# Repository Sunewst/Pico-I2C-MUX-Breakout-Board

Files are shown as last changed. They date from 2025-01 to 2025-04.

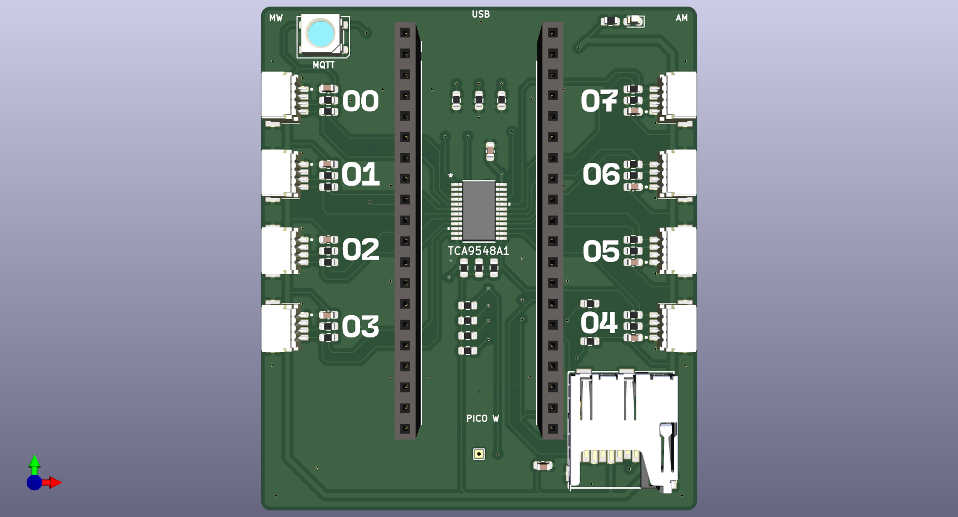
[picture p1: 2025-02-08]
Pico_STEMMA_HAT.png

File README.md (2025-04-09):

Showcase

<div align="center">

## Raspberry Pi Pico/W Breakout MUX Board

This PCB designed in KiCAD allows a Raspberry Pi Pico W, or normal version, to communicate with 8 I2C devices that have matching addresses. This board is based on breakout muiltiplexers sold by [Adafruit](https://www.adafruit.com/product/5626) and [SparkFun](https://www.sparkfun.com/sparkfun-qwiic-mux-breakout-8-channel-tca9548a.html). 

This also means the licence from these muiltiplexers, Creative Commons, applies to this one aswell.

</div>

---

## Arduino and CircuitPython
This breakout board works with either Arduino or CircuitPython.
> [!NOTE]
> For CircuitPython, I would recommend using the [libraries created by Adafruit for TCA9548a MUX use](https://learn.adafruit.com/adafruit-pca9548-8-channel-stemma-qt-qwiic-i2c-multiplexer/circuitpython-python).

The main connection are

SDA: GP4

SCL: GP5

MISO: GP16

MOSI: GP19

CLK: GP18

CS: GP17

Neopixel: GP6

---

## Creating and Changing this Design
1. Download the zip of this repo or clone it

2. Open the KiCAD project file.
> [!NOTE]
> This project was updated to KiCAD 9.0.

3. Examine and understand the schematic and PCB layout
> [!NOTE]
> The 3D models for the certain components might need to have their file path updated and their 3D models posistion adjusted to appear correctly on your PC.

4. Use your preferred PCB manufacture to order the PCB

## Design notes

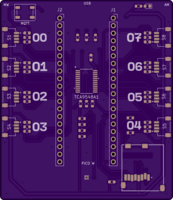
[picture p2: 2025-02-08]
STEMMA_HAT_FRONT.png

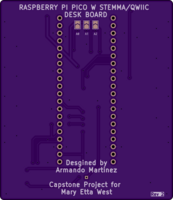
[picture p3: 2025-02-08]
STEMMA_HAT_BACK.png

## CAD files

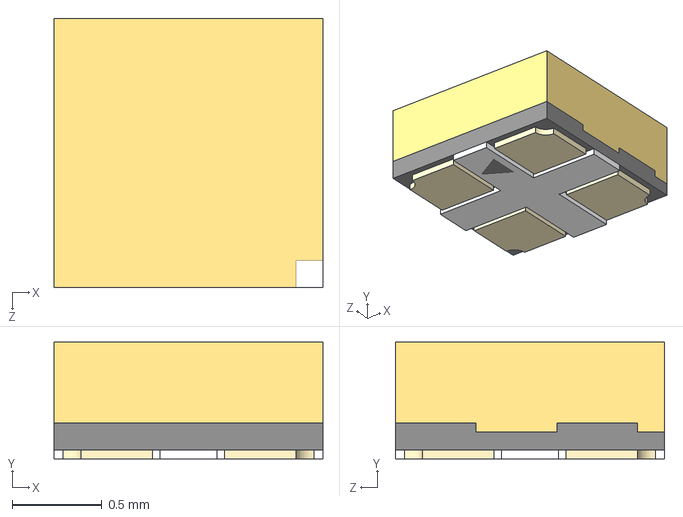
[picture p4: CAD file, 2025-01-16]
REIMAGINED_3D_FILES_BLENDER/4492.step
1.50 x 0.65 x 1.50 mm

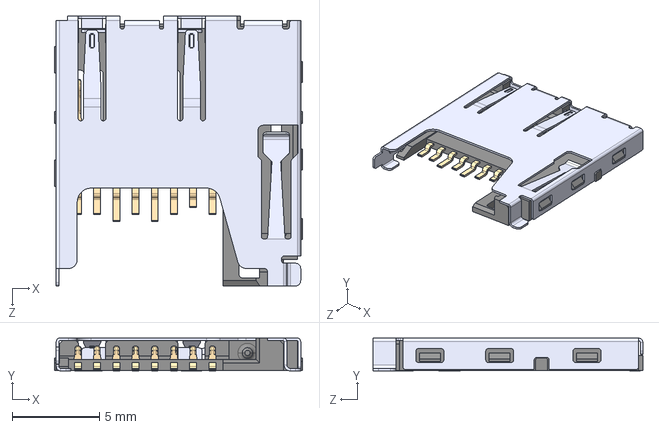
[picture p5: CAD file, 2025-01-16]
REIMAGINED_3D_FILES_BLENDER/MEM2061-01-188-00-A_REVA.step
14.2 x 1.88 x 15.4 mm

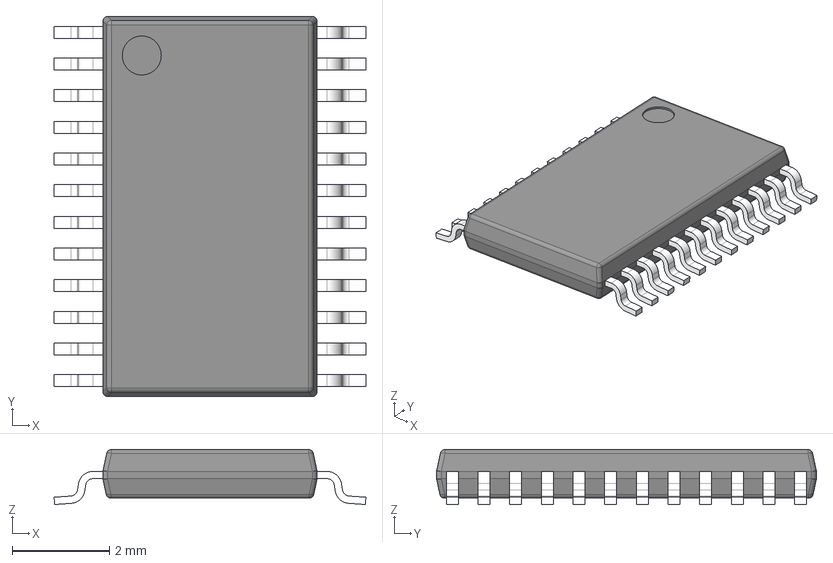
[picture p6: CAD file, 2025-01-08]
REIMAGINED_3D_FILES_BLENDER/PW0024A.stp
6.40 x 7.80 x 1.13 mm
BODY-TSSOP
LEAD-TSSOP x 24
PIN1

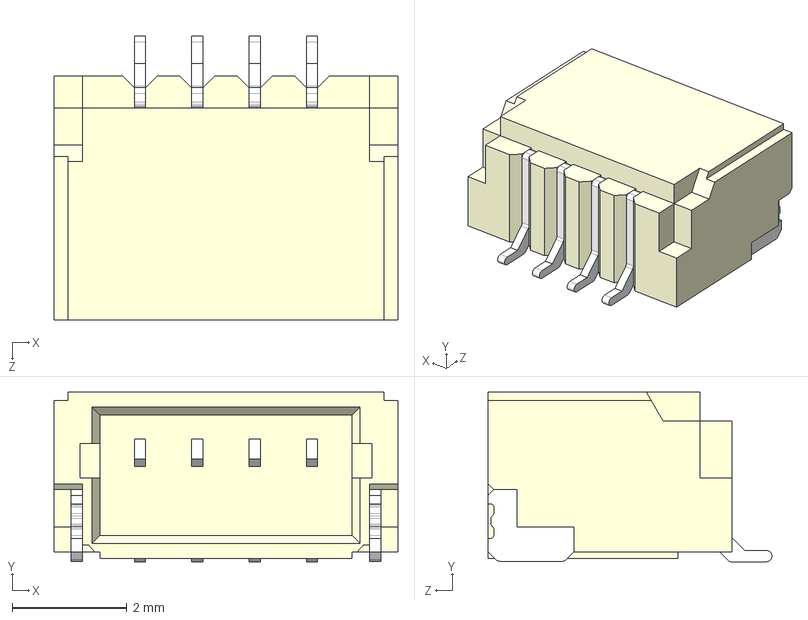
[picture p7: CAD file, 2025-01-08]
REIMAGINED_3D_FILES_BLENDER/PRT-14417.step
6.00 x 2.96 x 4.95 mm

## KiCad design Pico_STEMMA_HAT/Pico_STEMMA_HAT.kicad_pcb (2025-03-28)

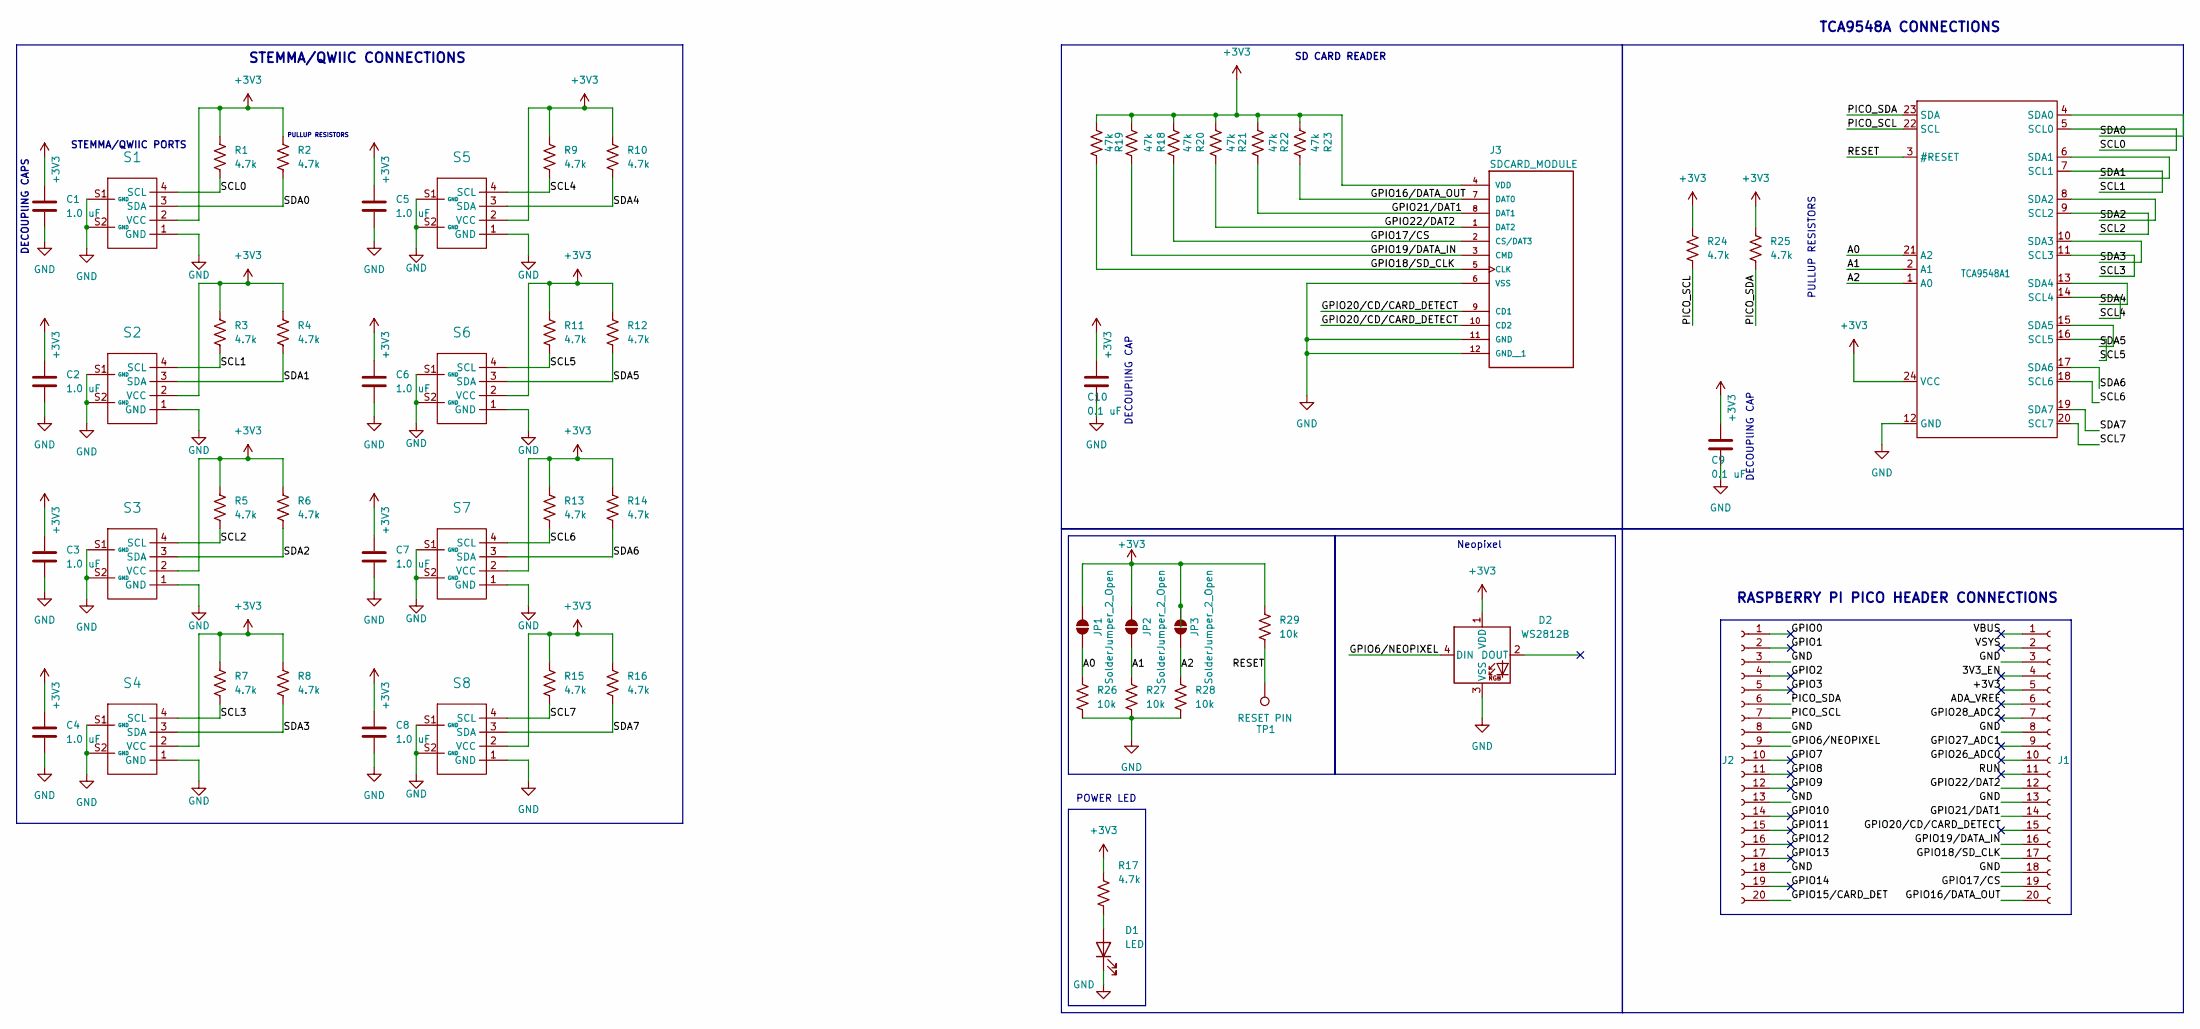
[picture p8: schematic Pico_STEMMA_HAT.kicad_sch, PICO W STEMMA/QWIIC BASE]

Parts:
C1, C2, C3, C4, C5, C6, C7, C8: 1.0 uF; C_0603_1608Metric
C9, C10: 0.1 uF; C_0603_1608Metric
D1: LED; LED_0603_1608Metric
D2: WS2812B; LED_WS2812B_PLCC4_5.0x5.0mm_P3.2mm
J1, J2: Conn_01x20_Socket; PinSocket_1x20_P2.54mm_Vertical
J3: SDCARD_MODULE; SDCARD_MODULE_Footprint
JP1, JP2, JP3: SolderJumper_2_Open; SolderJumper-2_P1.3mm_Open_TrianglePad1.0x1.5mm
R1, R2, R3, R4, R5, R6, R7, R8, R9, R10, R11, R12, R13, R14, R15, R16, R17, R24, R25: 4.7k; R_0603_1608Metric
R18, R19, R20, R21, R22, R23: 47k; R_0603_1608Metric
R26, R27, R28, R29: 10k; R_0603_1608Metric
S1, S2, S3, S4, S5, S6, S7, S8: STEMMAQWIIC_Footprint
TCA9548A1: TCA9548A_Footprint
TP1: RESET PIN; TestPoint_THTPad_1.0x1.0mm_Drill0.5mm

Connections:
+3V3: C1.1, C2.1, C3.1, C4.1, C5.1, C6.1, C7.1, C8.1, C9.1, C10.1, D2.1 (VDD), J1.5, J3.4 (VDD), JP1.2 (B), JP2.2 (B), JP3.2 (B), R1.1, R2.1, R3.1, R4.1, R5.1, R6.1, R7.1, R8.1, R9.1, R10.1, R11.1, R12.1, R13.1, R14.1, R15.1, R16.1, R17.1, R18.1, R19.1, R20.1, R21.1, R22.1, R23.1, R24.1, R25.1, R29.1, S1.2 (VCC), S2.2 (VCC), S3.2 (VCC), S4.2 (VCC), S5.2 (VCC), S6.2 (VCC), S7.2 (VCC), S8.2 (VCC), TCA9548A1.24 (VCC)
/3V3_EN: J1.4
/A0: JP1.1 (A), R26.1, TCA9548A1.21 (A2)
/A1: JP2.1 (A), R27.1, TCA9548A1.2 (A1)
/A2: JP3.1 (A), R28.1, TCA9548A1.1 (A0)
/ADA_VREF: J1.6
/GPIO0: J2.1
/GPIO1: J2.2
/GPIO2: J2.4
/GPIO3: J2.5
/GPIO6/NEOPIXEL: D2.4 (DIN), J2.9
/GPIO7: J2.10
/GPIO8: J2.11
/GPIO9: J2.12
/GPIO10: J2.14
/GPIO11: J2.15
/GPIO12: J2.16
/GPIO13: J2.17
/GPIO14: J2.19
/GPIO15/CARD_DET: J2.20
/GPIO16/DATA_OUT: J1.20, J3.7 (DAT0), R23.2
/GPIO17/CS: J1.19, J3.2 (CS/DAT3), R20.2
/GPIO18/SD_CLK: J1.17, J3.5 (CLK), R19.2
/GPIO19/DATA_IN: J1.16, J3.3 (CMD), R18.2
/GPIO20/CD/CARD_DETECT: J1.15, J3.9 (CD1), J3.10 (CD2)
/GPIO21/DAT1: J1.14, J3.8 (DAT1), R22.2
/GPIO22/DAT2: J1.12, J3.1 (DAT2), R21.2
/GPIO26_ADC0: J1.10
/GPIO27_ADC1: J1.9
/GPIO28_ADC2: J1.7
/PICO_SCL: J2.7, R24.2, TCA9548A1.22 (SCL)
/PICO_SDA: J2.6, R25.2, TCA9548A1.23 (SDA)
/RESET: R29.2, TCA9548A1.3 (#RESET), TP1.1
/RUN: J1.11
/SCL0: R1.2, S1.4 (SCL), TCA9548A1.5 (SCL0)
/SCL1: R3.2, S2.4 (SCL), TCA9548A1.7 (SCL1)
/SCL2: R5.2, S3.4 (SCL), TCA9548A1.9 (SCL2)
/SCL3: R7.2, S4.4 (SCL), TCA9548A1.11 (SCL3)
/SCL4: R9.2, S5.4 (SCL), TCA9548A1.14 (SCL4)
/SCL5: R11.2, S6.4 (SCL), TCA9548A1.16 (SCL5)
/SCL6: R13.2, S7.4 (SCL), TCA9548A1.18 (SCL6)
/SCL7: R15.2, S8.4 (SCL), TCA9548A1.20 (SCL7)
/SDA0: R2.2, S1.3 (SDA), TCA9548A1.4 (SDA0)
/SDA1: R4.2, S2.3 (SDA), TCA9548A1.6 (SDA1)
/SDA2: R6.2, S3.3 (SDA), TCA9548A1.8 (SDA2)
/SDA3: R8.2, S4.3 (SDA), TCA9548A1.10 (SDA3)
/SDA4: R10.2, S5.3 (SDA), TCA9548A1.13 (SDA4)
/SDA5: R12.2, S6.3 (SDA), TCA9548A1.15 (SDA5)
/SDA6: R14.2, S7.3 (SDA), TCA9548A1.17 (SDA6)
/SDA7: R16.2, S8.3 (SDA), TCA9548A1.19 (SDA7)
/VBUS: J1.1
/VSYS: J1.2
GND: C1.2, C2.2, C3.2, C4.2, C5.2, C6.2, C7.2, C8.2, C9.2, C10.2, D1.1 (K), D2.3 (VSS), J1.3, J1.8, J1.13, J1.18, J2.3, J2.8, J2.13, J2.18, J3.6 (VSS), J3.11 (GND), J3.12 (GND__1), R26.2, R27.2, R28.2, S1.1 (GND), S1.S1 (GND), S1.S2 (GND), S2.1 (GND), S2.S1 (GND), S2.S2 (GND), S3.1 (GND), S3.S1 (GND), S3.S2 (GND), S4.1 (GND), S4.S1 (GND), S4.S2 (GND), S5.1 (GND), S5.S1 (GND), S5.S2 (GND), S6.1 (GND), S6.S1 (GND), S6.S2 (GND), S7.1 (GND), S7.S1 (GND), S7.S2 (GND), S8.1 (GND), S8.S1 (GND), S8.S2 (GND), TCA9548A1.12 (GND)
unnamed: D1.2 (A), R17.2

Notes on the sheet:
STEMMA/QWIIC PORTS
SD CARD READER
RASPBERRY PI PICO HEADER CONNECTIONS
DECOUPlING CAP
TCA9548A CONNECTIONS
PULLUP RESISTORS
DECOUPlING CAPS
STEMMA/QWIIC CONNECTIONS
POWER LED
Neopixel

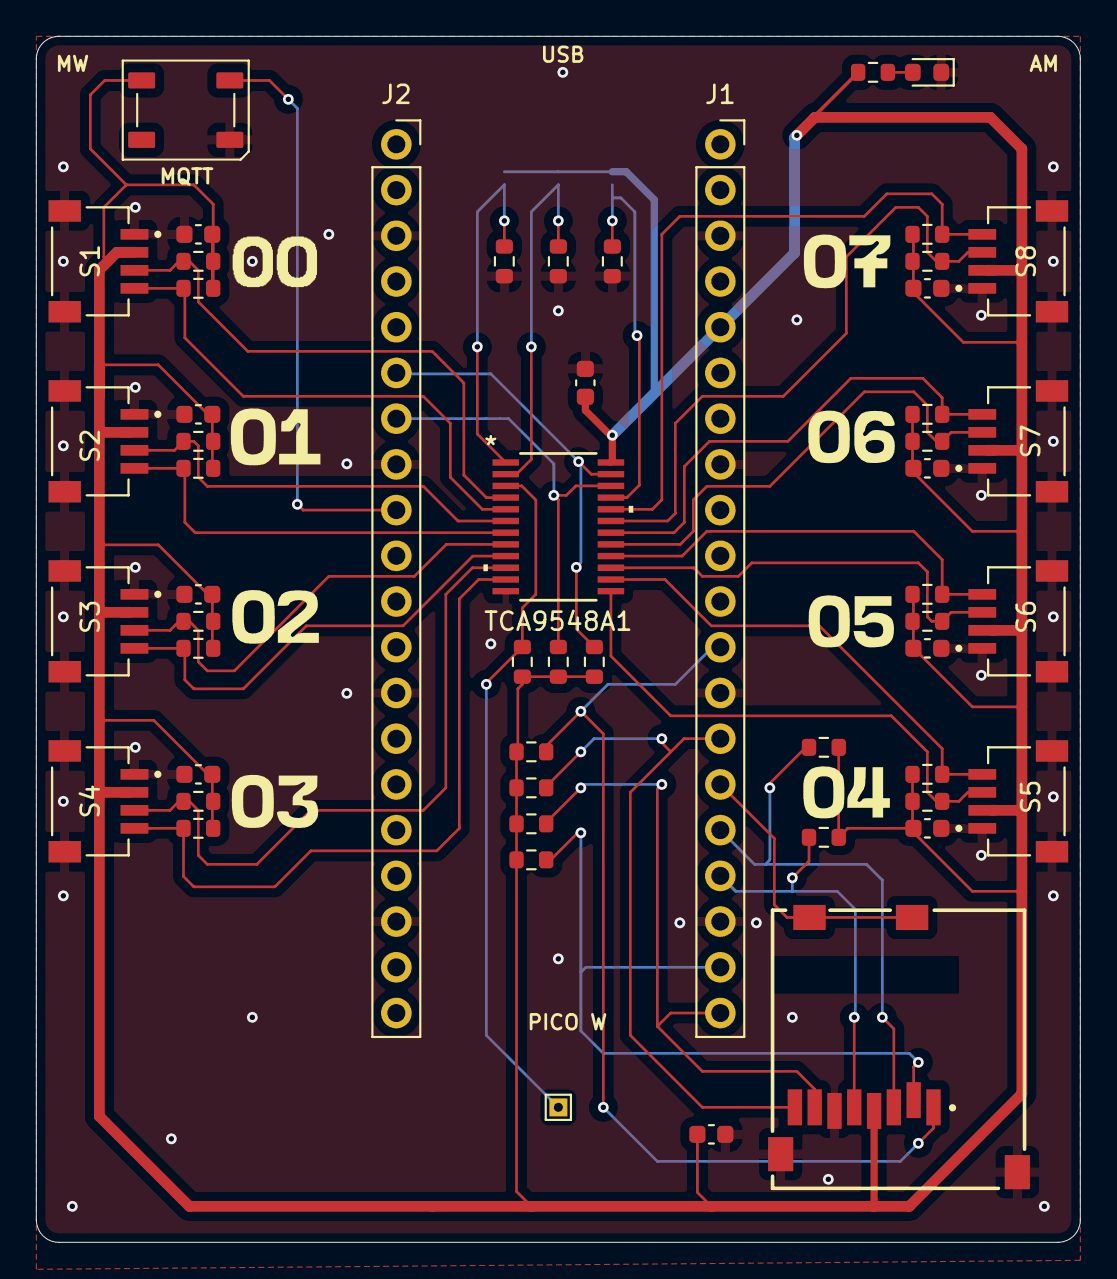
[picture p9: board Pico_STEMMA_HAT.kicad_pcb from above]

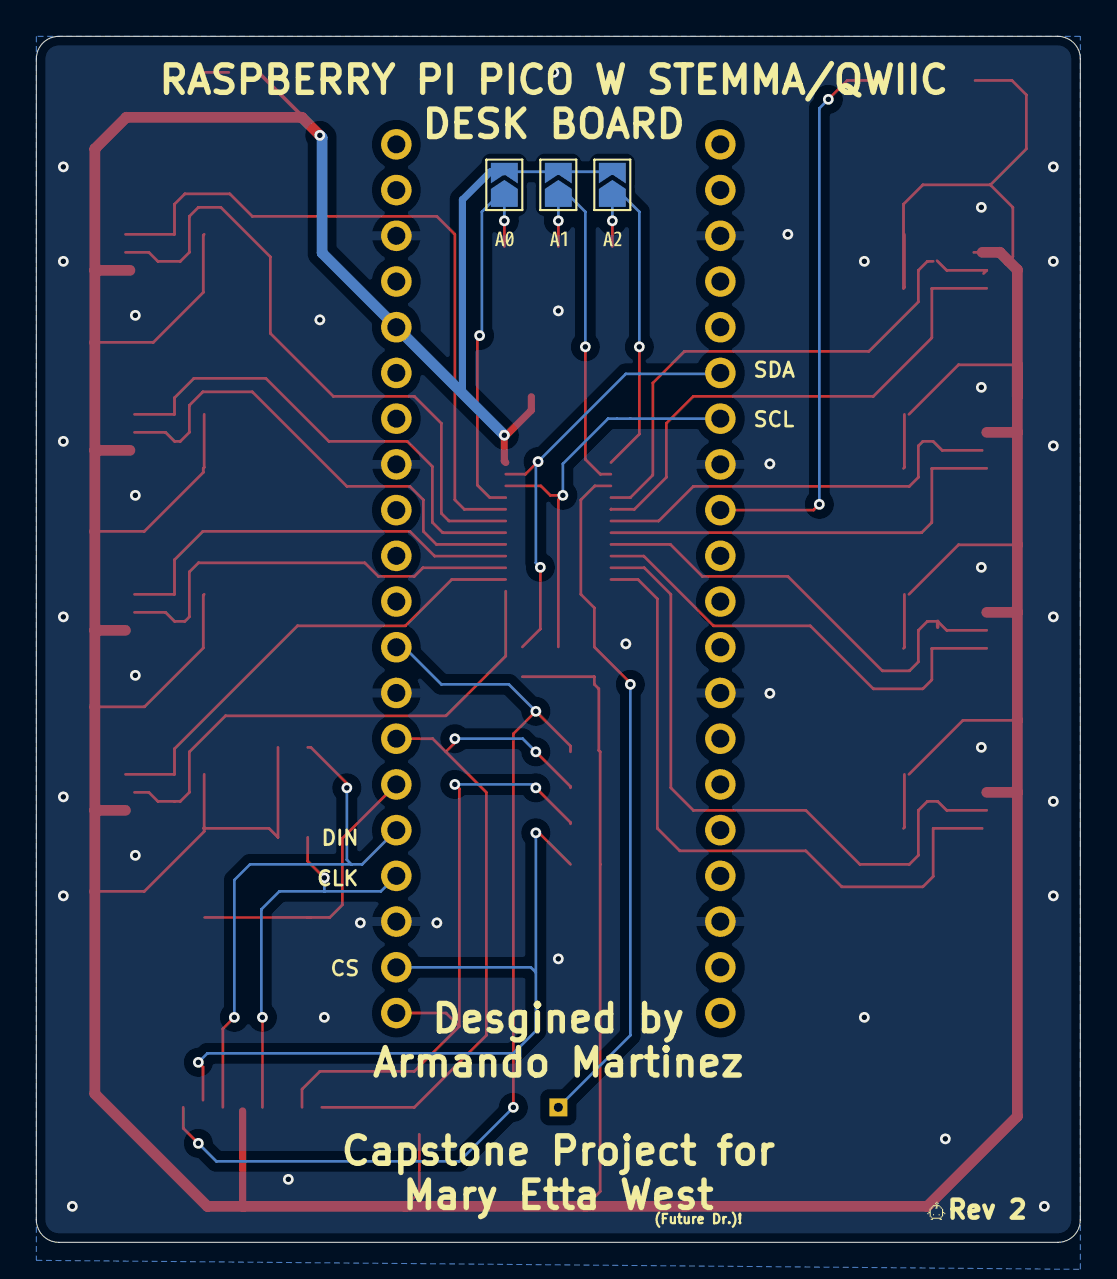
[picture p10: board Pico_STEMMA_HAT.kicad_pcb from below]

Board: 2 copper layers, 58.0 x 67.0 mm, 60 parts (6 on the bottom side), 33 nets.

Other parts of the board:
kibuzzard-67A6AC81: G***; kibuzzard-67A6AC81
kibuzzard-67A6B903: G***; kibuzzard-67A6B903
kibuzzard-67A6E024: G***; kibuzzard-67A6E024

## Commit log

2025-01-05 Add Winter Break Progress
    Progress so far from learning KiCAD and creating the Pico W base over break. The SD card and coin battery will be added tomorrow when I create their footprints.
    [Pico_STEMMA_HAT.kicad_pcb, Pico_STEMMA_HAT.kicad_sch]
2025-01-05 Add STEMMA connector pads to the GND net
    [Pico_STEMMA_HAT.kicad_pcb, Pico_STEMMA_HAT.kicad_sch]
2025-01-05 Add 3D models for STEMMA connectors and TCA9548A
    [Pico_STEMMA_HAT.kicad_pcb]
2025-01-06 Fix errors from the DRC
    The design rules are based around the JLCPCB manufacturer
    [Pico_STEMMA_HAT.kicad_pcb, Pico_STEMMA_HAT.kicad_sch]
2025-01-06 Rearranged traces
    [Pico_STEMMA_HAT.kicad_pcb]
2025-01-06 Reroute traces
    [Pico_STEMMA_HAT.kicad_pcb]
2025-01-08 Add 3D models to the repo
    [PRT-14417.step, PW0024A.stp, Pico_STEMMA_HAT.kicad_pcb]
2025-01-09 Add SD Card symbol and footprint
2025-01-09 Fix 3D model rendering in MacOS
    [Pico_STEMMA_HAT.kicad_pcb, Pico_STEMMA_HAT.kicad_sch]
2025-01-11 Add GND vias to connect STEMMA GNDs
    [Pico_STEMMA_HAT.kicad_pcb]
2025-01-11 Add GND vias to connect to GND B layer
    [Pico_STEMMA_HAT.kicad_pcb]
2025-01-15 Add SD Card reader to schem
    [Pico_STEMMA_HAT.kicad_sch]
2025-01-15 Add SD card reader to PCB design
    [Pico_STEMMA_HAT.kicad_pcb, Pico_STEMMA_HAT.kicad_sch]
2025-01-15 Add pullup resistors to the SD card reader
    [Pico_STEMMA_HAT.kicad_pcb, Pico_STEMMA_HAT.kicad_sch]
2025-01-15 Adjust traces
    [Pico_STEMMA_HAT.kicad_pcb]
2025-01-16 Change pullup resistors
    [MEM2061-01-188-00-A_REVA.step, Pico_STEMMA_HAT.kicad_pcb, Pico_STEMMA_HAT.kicad_sch]
2025-01-16 Add 3D models for SD card and Neopixel
    [4492.step]
2025-01-16 Fix STEMMA GND Nets
    [Pico_STEMMA_HAT.kicad_pcb, Pico_STEMMA_HAT.kicad_sch]
2025-01-16 Add PNG of the 3D model of the board
    [Pico_STEMMA_HAT.kicad_pcb]
2025-01-16 Fix SD Card connections
    [Pico_STEMMA_HAT.kicad_pcb, Pico_STEMMA_HAT.kicad_sch]
2025-01-16 Fix MacOS 3D models
    [Pico_STEMMA_HAT.kicad_pcb]
2025-01-18 Adjust traces according to oshpark DRC
    [Pico_STEMMA_HAT.kicad_pcb]
2025-01-21 Add STEMMA numbers and credits
    [Pico_STEMMA_HAT.kicad_pcb]
2025-01-21 Adjust silkscreen
    [Pico_STEMMA_HAT.kicad_pcb, Pico_STEMMA_HAT.kicad_sch]
2025-01-21 Fix fonts
    [Pico_STEMMA_HAT.kicad_pcb]
2025-01-22 Add decoupling cap for the SD card reader
    [Pico_STEMMA_HAT.kicad_pcb, Pico_STEMMA_HAT.kicad_sch]
2025-01-23 Add Gameboy Color ref
    [Pico_STEMMA_HAT.kicad_pcb]
2025-02-07 Fix pull-up resistors for multiplexer
    Add the pull-up resistors from the schem to the PCB design. Adjusted resistor value for red LED. Adjusted Neopixel footprint.
    [Pico_STEMMA_HAT.kicad_sch]
2025-02-07 Change 3D model preview image
    [Pico_STEMMA_HAT.kicad_pcb]
2025-02-07 Change page settings
    [Pico_STEMMA_HAT.kicad_pcb, Pico_STEMMA_HAT.kicad_sch]
2025-02-07 Fix Neopixel footprint
    [Pico_STEMMA_HAT.kicad_pcb, Pico_STEMMA_HAT.kicad_sch]
2025-02-07 Adjust through-hole connectors
    [Pico_STEMMA_HAT.kicad_pcb]
2025-02-08 Add the ability to change multiplexer address
    [Pico_STEMMA_HAT.kicad_pcb, Pico_STEMMA_HAT.kicad_sch]
2025-02-08 Adjust SD card pin for OCD-reasons
    [Pico_STEMMA_HAT.kicad_pcb, Pico_STEMMA_HAT.kicad_sch]
2025-02-08 Fix pin name
2025-02-08 Adjust sch layout
    [Pico_STEMMA_HAT.kicad_sch]
2025-02-08 Change reset pin to be out in the open
    [Pico_STEMMA_HAT.kicad_pcb, Pico_STEMMA_HAT.kicad_sch]
2025-02-08 Adjust reset pin trace
    [Pico_STEMMA_HAT.kicad_pcb]
2025-02-08 Add oshpark order front and back side PCB view
2025-02-10 Add silkscreen appreciation
    [Pico_STEMMA_HAT.kicad_pcb]
2025-03-04 Update schematic formatting
    [Pico_STEMMA_HAT.kicad_pcb, Pico_STEMMA_HAT.kicad_sch]
2025-03-04 Update schematic
    [Pico_STEMMA_HAT.kicad_pcb, Pico_STEMMA_HAT.kicad_sch]
2025-03-28 Adjust vias
    [Pico_STEMMA_HAT.kicad_pcb]
